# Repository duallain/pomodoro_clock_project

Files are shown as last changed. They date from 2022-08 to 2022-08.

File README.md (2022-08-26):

# pomodoro_clock_project
 A hobby electronics project

# General info

Pomodoros are a technique for trying to stay productive throught the day. You work for a bit, then take a break, alternate back and forth between those two, then take a longer break. I find it helpful to get focus during the work time, but not completely tire myself out. I couldn't find a physical clock I loved, and the 7 segment displays are so cool, I decided to try and build my own. And it seemed to turn out ok :)

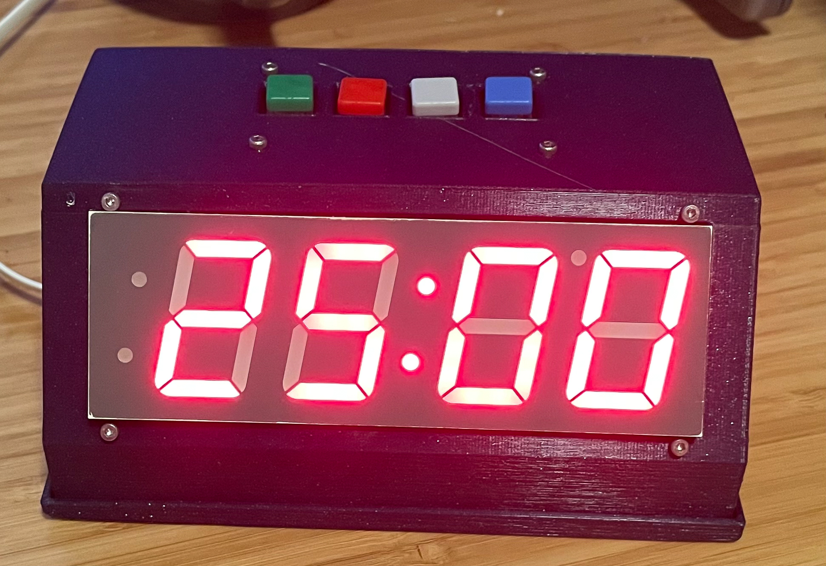
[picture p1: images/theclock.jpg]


# button pcb
 I ended up having quite a bit of trouble assembling a nice button layout on protoboards, so ended up buying 3 of the boards from osh park. The kicad files are all included in button_pcb, feel free to get some of your own manufactered.

# the case

There's a case for everything I modeled with onshape, link in the readme in case_model. Also included the stl. It's not the most efficent case, but it holds the display at a nice angle, gives space for the buttons to come throw, and they can be clicked, and hides all the wires and such. This will take a good minute to print, and I found the best orientation was the top (with the button holes) down against build plate, with supports for the display.

# Assembly

### solder headers to pi pico
Solder the headers to the pi pico, I went 'backwards', putting the long parts facing towards the labeled side of the pico, it makes hitting the bootsel button harder, but easier to assemble later. I soldered both rows, but didn't add the headers to the 3 debug pins on the short ends.

This article has tons of good info, and there's lots of videos showing how to do it, but essentially solder the male headers, short end through the board. https://magpi.raspberrypi.com/articles/how-to-solder-gpio-pin-headers-to-raspberry-pi-pico (I use the breadboard method and it works wonderfully.)

I highly recommend having the pin out somewhere handy, either printed out or up on a computer. https://datasheets.raspberrypi.com/pico/Pico-R3-A4-Pinout.pdf

### assemble the 7 segment display

Follow this guide, https://learn.adafruit.com/adafruit-led-backpack/1-2-inch-7-segment-backpack-assembly

You essentially put the backpack and display together, solder all the legs, then put in a 1x5 header, solder that in and you're done.

### assemble the buttons

if you have the pcb assembly is really straight forward. On the labled side you'll snap the buttons into place. There are 4 through holes per button, plus two alignment holes. Solder those in place. I found that snapping the buttons in worked great, they have plenty of strength to be flipped over and soldered. Orientation doesn't matter, they're symmetrical. You likely don't need to clip the leads, but can if you wish.
Then add the resistors. You should put these all on the non-labeled side. Solder then clip. Orientation doesn't matter here either.
Add the two headers, long side on the same side as the resistors (the 'bottom' of the pcb). the short bit should be on the same side as the buttons.

### the case

I used m2 screws everywhere, m2x12 to be exact, and washers and nuts. That worked for mounting both the button pcb and the display. I did this before continuing. You push the screw through the front, then put a washer/nut on it. Hold the nut with your finger, then turn the screw a bit. Do this for all 4 bolts, then go around again and tighten everything.  I had to hold the nuts with a pair of needle nose pliers, but if you had a tiny little 2 mm socket that'd be ideal.

### connecting things together

You can change pins if you wish, you'll just need to change the code.

You can pre make the cables, the 6 strand one is for button to pi. 5 strand is for display to pi. I'll label how many of the headers to use in each connection, but it's asymmetric, so be careful here. This is basically to save us from having to make a 2nd pcb to group pi pins together like we need.

Make all of these connections:

button pcb 1x2 header -> (with the 6 strand cable) 1 1x2 header to 2 1x1 headers -> 3.3v and gnd (GPIO 37/33). The square pad on the button pcb is the power, use a nice bright color
button pcb 1x4 header -> (with the 6 strand cable) 1 1x4 header to 1 1x4 header -> any 4 gpio in a row (gpio10-13). You may need to change pins in the code, but any 4 gpio work. To use current code, and get buttons left to right as start/stop/reset/next, connect the square pad to gpio 10.

7 seg display 1x5 header -> (with 5 strand cable) 1 1x5 header to 1x3 and 1x2 ->
1x2 header to gp 21 and 20, the scl pin on the display goes to gp21, while sda goes to gp20.
1x3 connects to vbus/vsys/ground, gound is labeled on the display, and the +5v/v_io connect to the other two pins. Doesn't really matter which, but since they're in a row there's really only one way for it to all connect.

### programming

I used arduino ide 2.x, installed the libraries called for in the code, and then plugged in the pi pico to my computer while holding the bootsel. Click upload and it should (if everything goes well) just work. The display should be on, with the time for the first pomodoro.
Click start to start counting down. Stop to stop. Reset to start from the existing timer, and next to go to the next timer. The buttons are in that order left to right while you're looking at the display.

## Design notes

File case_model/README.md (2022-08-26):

With a warning that I'm not the best modeler, sharing this anyway since it might be useful.

There's a case and a tray modeled
The important bits here are the button spacing, the hole locations.
The tray is optional, I just thought a bottom might be nice.

Onshape document is here:
https://cad.onshape.com/documents/60f3f35189f511c7e30edd43/w/157a73a1e206ba1b478c3d50/e/2b710410ca02501ef277f9ce

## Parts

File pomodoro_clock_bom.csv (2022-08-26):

Query | Qty | Manufacturer | MPN | Octopart URL | Part Description | Description | Schematic Reference | Internal Part Number | Lifecycle | Lead Time | RoHS | Total Qty (@ Batch Size: 1) | SKU | SKU | SKU | SKU | SKU | Packaging | Packaging | Packaging | Packaging | Packaging | Unit Price (@ Batch Size: 1) | Unit Price (@ Batch Size: 1) | Unit Price (@ Batch Size: 1) | Unit Price (@ Batch Size: 1) | Unit Price (@ Batch Size: 1) | In Stock | In Stock | In Stock | In Stock | In Stock | MOQ | MOQ | MOQ | MOQ | MOQ | URL | URL | URL | URL | URL | Distributor [Lowest Price (Selected)] | SKU [Lowest Price (Selected)] | Packaging [Lowest Price (Selected)] | Unit Price (@ Batch Size: 1) [Lowest Price (Selected)] | Line Total [Lowest Price (Selected)] | Batch Total [Lowest Price (Selected)] | In Stock [Lowest Price (Selected)] | MOQ [Lowest Price (Selected)] | URL [Lowest Price (Selected)] | Notes
 |  |  |  |  |  |  |  |  |  |  |  |  | Digi-Key | Mouser | Newark | Onlinecomponents.com | RS Components | Digi-Key | Mouser | Newark | Onlinecomponents.com | RS Components | Digi-Key | Mouser | Newark | Onlinecomponents.com | RS Components | Digi-Key | Mouser | Newark | Onlinecomponents.com | RS Components | Digi-Key | Mouser | Newark | Onlinecomponents.com | RS Components | Digi-Key | Mouser | Newark | Onlinecomponents.com | RS Components
ADA1010 | 4 | Adafruit Industries | 1010 | https://octopart.com/1010-adafruit+industries-32978107 | Colorful 12Mm Square Tactile Button Switch Assortment - 15 Pack | Buy as a single set of 10 to get 4 buttons, or buy for 653-B3F-4050 (mouser), 12mmx12mm tactile switches |  |  |  | 2w | Non-Compliant | 4 | 1528-2151-ND | 485-1010 | 53W5647 |  |  | Bulk |  |  |  |  | 5.95 | 5.95 | 5.95 |  |  | 20 | 39 | 0 |  |  | 1 | 1 | 1 |  |  | https://octopart.com/opatz8j6/a1 | https://octopart.com/opatz8j6/a1 | https://octopart.com/opatz8j6/a1 |  |  | Mouser | 485-1010 |  | 5.95 | 23.8 | 23.8 | 39 | 1 | https://octopart.com/opatz8j6/a1
ADA3145 | 1 | Adafruit Industries | C4846 | https://octopart.com/c4846-adafruit+industries-128533651 | Small Single Row Wire Housing Pack for DIY Jumper Cables | you need (qty, header) [(1,1x5), (2,1x2),(1,1x3),(2,1x1),(2,1x4)] |  |  |  |  |  | 1
1x5 wire housing | 1 |  |  |  |  | from the ADA3145 pack which will cover all quantity needed, but listing all just in case you need to check inventory |  |  |  |  |  | 1
1x2 wire housing | 2 |  |  |  |  | from the ADA3145 pack which will cover all quantity needed, but listing all just in case you need to check inventory |  |  |  |  |  | 2
1x3 wire housing | 1 |  |  |  |  | from the ADA3145 pack which will cover all quantity needed, but listing all just in case you need to check inventory |  |  |  |  |  | 1
1x1 wire housing | 2 |  |  |  |  | from the ADA3145 pack which will cover all quantity needed, but listing all just in case you need to check inventory |  |  |  |  |  | 2
4x4 wire housting | 2 |  |  |  |  | from the ADA3145 pack which will cover all quantity needed, but listing all just in case you need to check inventory |  |  |  |  |  | 2
ADA4864 | 1 | Raspberry Pi | ADA4864 | https://octopart.com/ada4864-raspberry+pi-116090675 | Raspberry Pi Pico RP2040 |  |  |  |  |  |  | 1
ADA1270 | 1 | Adafruit Industries | 1270 | https://octopart.com/1270-adafruit+industries-32978309 | Adafruit 1.2 4-Digit 7-Segment Display W/i2C Backpack - Red Rohs Compliant: Yes | Feel free to choose a different color, but the backpack is essential, and the 1.2" display is great |  |  |  | 2w | Compliant | 1 | 1528-1876-ND | 485-1270 | 89W0287 |  |  | Bulk |  |  |  |  | 17.5 | 17.5 | 17.5 |  |  | 26 | 79 | 0 |  |  | 1 | 1 | 1 |  |  | https://octopart.com/opatz8j6/a1 | https://octopart.com/opatz8j6/a1 | https://octopart.com/opatz8j6/a1 |  |  | Mouser | 485-1270 |  | 17.5 | 17.5 | 17.5 | 79 | 1 | https://octopart.com/opatz8j6/a1
ADA3141 | 1 | Adafruit Industries | 3141 | https://octopart.com/3141-adafruit+industries-75118751 | Premium Female/Female Raw Custom Jumper Wires - 40 x 6" (150mm) | we'll break this up as part of construction, you'll end up needing 5 grouped together, and 6 together. |  |  |  | 2w |  | 1 | 1528-2176-ND | 485-3141 | 48AC7939 |  |  | Bulk |  |  |  |  | 2.95 | 2.95 | 2.95 |  |  | 42 | 21 | 0 |  |  | 1 | 1 | 1 |  |  | https://octopart.com/opatz8j6/a1 | https://octopart.com/opatz8j6/a1 | https://octopart.com/opatz8j6/a1 |  |  | Mouser | 485-3141 |  | 2.95 | 2.95 | 2.95 | 21 | 1 | https://octopart.com/opatz8j6/a1
ADA392 | 1 | Adafruit Industries | DENKE DK501-1X36-12; 4UCON20447 | https://octopart.com/denke+dk501-1x36-12%3B+4ucon20447-adafruit+industries-128533765 | Break-away 0.1" 36-pin strip male header - Black - 10 pack | a few headers, this is way too many, but figured it'd be easy to throw in an order |  |  |  |  |  | 1
ADA4294 | 4 | Adafruit Industries | YAGEO CFR-25JR-52-1K OR EQUIV | https://octopart.com/yageo+cfr-25jr-52-1k+or+equiv-adafruit+industries-128534662 | Through-Hole Resistors - 1.0K ohm 5% 1/4W - Pack of 25 | doesn't matter too much what value, but you need 4 resistors |  |  |  |  |  | 4

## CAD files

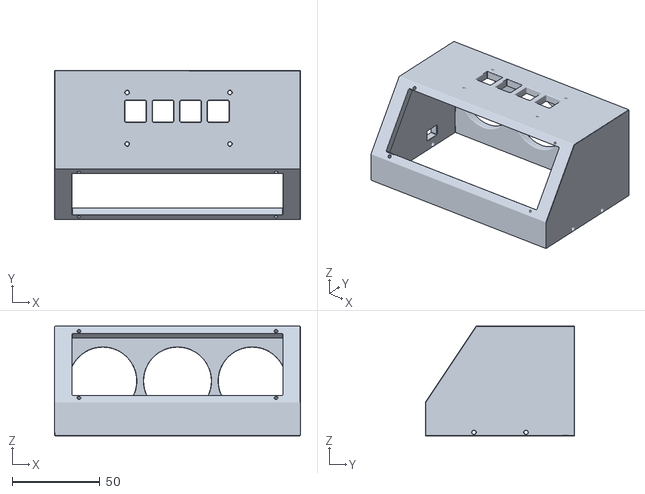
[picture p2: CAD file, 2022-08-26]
case_model/Case.stl
140.0 x 85.0 x 62.5

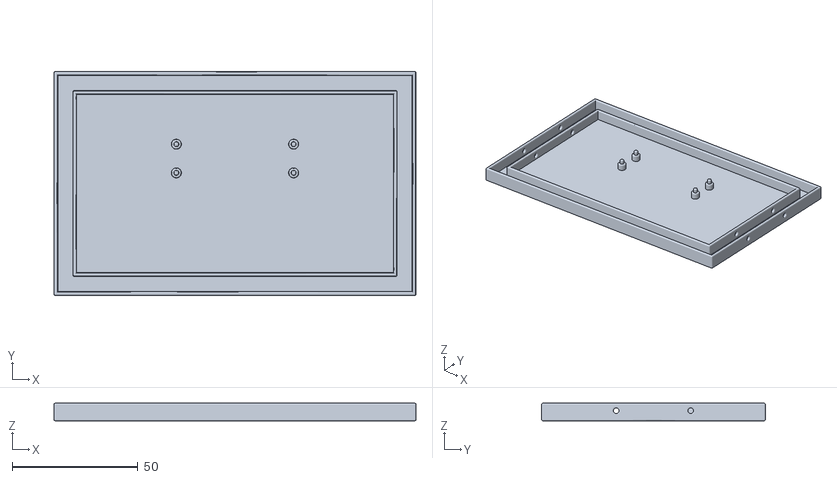
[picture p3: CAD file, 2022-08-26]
case_model/Tray.stl
144.0 x 89.0 x 7.00

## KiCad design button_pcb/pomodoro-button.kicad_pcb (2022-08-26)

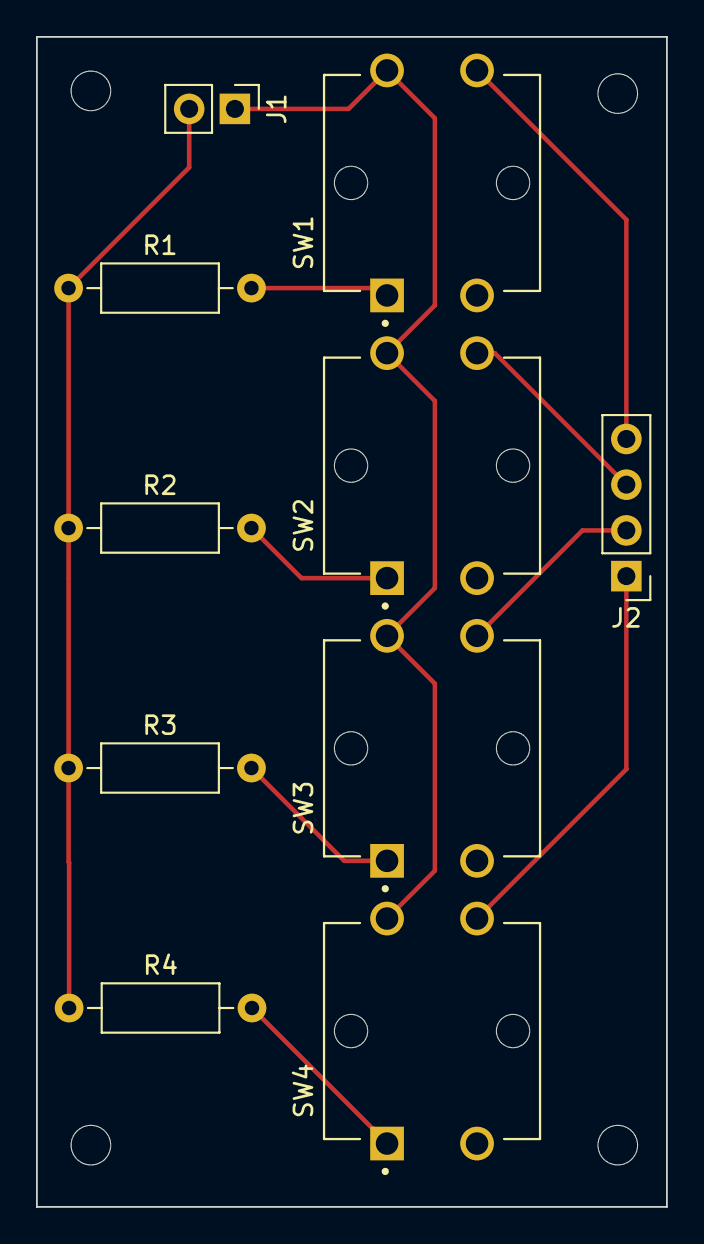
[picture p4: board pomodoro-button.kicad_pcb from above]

Board: 2 copper layers, 35.0 x 65.0 mm, 10 parts (0 on the bottom side), 10 nets.

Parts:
J1: Conn_01x02_Male; PinHeader_1x02_P2.54mm_Vertical
J2: Conn_01x04; PinHeader_1x04_P2.54mm_Vertical
R1, R2, R3, R4: 1000; R_Axial_DIN0207_L6.3mm_D2.5mm_P10.16mm_Horizontal
SW1, SW2, SW3, SW4: SW_MEC_5E; SW_B3F-4050

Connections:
+3V3: J1.1, SW1.2, SW2.2, SW3.2, SW4.2
GND: J1.2, R1.1, R2.1, R3.1, R4.1
unnamed: J2.1, SW4.4
unnamed: J2.2, SW3.4
unnamed: J2.3, SW2.4
unnamed: J2.4, SW1.4
unnamed: R1.2, SW1.1
unnamed: R2.2, SW2.1
unnamed: R3.2, SW3.1
unnamed: R4.2, SW4.1

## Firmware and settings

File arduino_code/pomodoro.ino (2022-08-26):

#include <Automaton.h> // https://github.com/tinkerspy/Automaton/wiki
#include <Wire.h>  //
#include <Adafruit_GFX.h> // https://github.com/adafruit/Adafruit-GFX-Library
#include "Adafruit_LEDBackpack.h" // https://learn.adafruit.com/adafruit-led-backpack/downloads

// These are the two gpio ports that the matrix is connected to for i2c
const byte PICO_I2C_SDA = 20;
const byte PICO_I2C_SCL = 21;

// 7 seg object, and a setup bool to track if it's been setup
Adafruit_7segment matrix = Adafruit_7segment();
bool matrix_setup = false;

// gpio pin of each button
const int startButtonPin = 13;
const int stopButtonPin = 12;
const int resetButtonPin = 11;
const int nextButtonPin = 10;


// creating the automaton state machine objects
Atm_timer countdown;
Atm_button startButton, stopButton, nextButton, resetButton;

// real times
int pomodoro = 25 * 60;
int short_break = 5 * 60;
int long_break = 30 * 60;

// this holds the pattern between work periods and breaks
int timer_array[] = { pomodoro, short_break, pomodoro, short_break, pomodoro, short_break, pomodoro, long_break };
int array_count = sizeof timer_array / sizeof timer_array[0];
int timer_loc = 0;


void setup() {
  Serial.begin(9600);

  countdown.begin(1000)
    .onTimer(timer_tick_callback)
    .onFinish(timer_finish_callback);

  startButton
    .begin(startButtonPin)
    .onPress(start_button_press);

  stopButton
    .begin(stopButtonPin)
    .onPress(stop_button_press);

  resetButton
    .begin(resetButtonPin)
    .onPress(reset_button_press);

  nextButton
    .begin(nextButtonPin)
    .onPress(next_button_press);


  while (matrix_setup == false) {
    Serial.println("setting up matrix");
    Wire.setSDA(PICO_I2C_SDA);
    Wire.setSCL(PICO_I2C_SCL);
    matrix_setup = matrix.begin(0x70, &Wire);
    delay(50);
  }

  // start the state machine in idle, so we display some numbers
  idle();
}

void loop() {
  automaton.run();
}

// state functions/callbacks
// while the timer is running, gets called once a second
// (configured by the value passed to begin for the countdown object)
void timer_tick_callback(int idx, int v, int up) {
  display_number(v);
}

// when timer completes the vale of cycles from repeat(value), this function is called
void timer_finish_callback(int idx, int v, int up) {
  display_number(0);
  delay(1000);  // should I make a new timer here and call idle only on it's finish? Leaving here for now -- no real need to not block
  idle();
}

void start_button_press(int idx, int v, int up) {
  countdown.start();
}

void stop_button_press(int idx, int v, int up) {
  countdown.stop();
}

void next_button_press(int idx, int v, int up) {
  if (countdown.state() == countdown.IDLE) {
    idle();
  }
}

// to reset, while stopped, go back one timer, and then go to IDLE
// this essentially sets everything up as if we're starting the current timer over
void reset_button_press(int idx, int v, int up) {
  if (countdown.state() == countdown.IDLE) {
    timer_loc--;
    idle();
  }
}

// states

// idle state, is the first state, and also the state we return to when timer completes
// the other states are mostly implicit from an event occuring, like a button press
void idle() {
  int timer_value = timer_array[timer_loc % array_count];
  display_number(timer_value);
  countdown.repeat(timer_value);
  timer_loc++;
}


// helper functions
int seconds_to_minutes_and_seconds(int counter) {
  int seconds = counter % 60;
  int minutes = counter / 60;

  return seconds + 100 * minutes;
}


void display_number(int num) {
  matrix.print(seconds_to_minutes_and_seconds(num));
  matrix.drawColon(true);
  matrix.writeDisplay();
}

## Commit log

2022-08-26 Adding pcb I designed to hold the 4 buttons
    [pomodoro-button.kicad_pcb, pomodoro-button.sch]
2022-08-26 Case Model
    [Case.stl, Tray.stl]
2022-08-26 adding a bill of materials
    [pomodoro_clock_bom.csv]
2022-08-26 build info and some small updates
    [pomodoro_clock_bom.csv]
